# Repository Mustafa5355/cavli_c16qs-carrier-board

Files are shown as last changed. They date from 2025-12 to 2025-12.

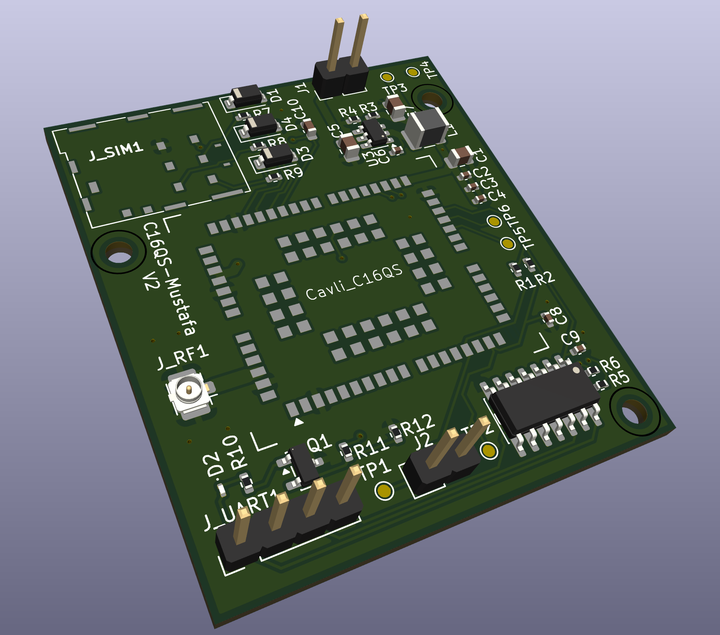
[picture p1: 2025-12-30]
PCB/c16qs-carrier-board.png

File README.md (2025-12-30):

# cavli_c16qs-carrier-board

This repository contains the complete hardware design for a 2-layer carrier board for the Cavli C16QS LTE Cat-1 bis module. The board provides regulated power, SIM card interface, RF antenna connection via u.FL, level-shifted UART communication to a 3.3 V host, and control/status signals.

The design is implemented in KiCad and follows Cavli's hardware guidelines for power integrity, RF layout, and SIM protection. It is intended as a reference carrier for evaluation, prototyping, and integration of the C16QS module into embedded systems.

Features:
- 5 V input with synchronous buck regulation to module VBAT
- Nano-SIM socket with ESD protection and signal conditioning
- u.FL connector for external LTE antenna
- Bidirectional UART level shifting between 1.8 V and 3.3 V domains
- Hardware power key, reset, and network status indication
- 2-layer, low-cost PCB optimized for EMI and signal integrity

The repository includes schematic, PCB layout, fabrication outputs, BOM, and design documentation.

## Footprint Note

The C16QS footprint included in this repository was created manually by the author using the published mechanical drawings and pin mapping of the C16QS module. It is designed to be reusable across projects and is suitable for prototyping and evaluation.

This footprint is not an official manufacturer CAD file. Users should verify alignment and pin mapping against the latest Cavli documentation before fabrication.

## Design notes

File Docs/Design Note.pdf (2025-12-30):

## Design Note — C16QS Carrier Board (v1)

### 1. Functional Overview

This board is a minimal-component carrier for the Cavli C16QS LTE Cat-1 bis module. It provides regulated power, level-shifted UART, SIM card interface, RF antenna connection, hardware control signals, and basic debug access.

The design follows Cavli’s reference hardware requirements for power, RF routing, SIM connectivity, and control interfaces.

### 2. Power Architecture

The board is powered from a 5 V external supply connected at J1. A synchronous buck regulator (AP62250WU) generates the module supply voltage VBAT.

The regulator output is set using the resistor divider R3 and R4 to approximately 3.8 V, which lies safely within the C16QS operating range.

The inductor L1 and capacitors C6 and C7 form the switching and output filter network recommended in the regulator datasheet. Additional local decoupling capacitors (C1–C4) are placed directly at the module’s VBAT pins to handle high-frequency current transients during LTE transmission.

The regulator is sized to handle the module’s peak current during transmit bursts, providing sufficient margin above the expected maximum load.

### 3. UART Level Shifting

The C16QS uses 1.8 V logic levels, while the external host operates at 3.3 V. A TXS0104ED bidirectional level translator is used to safely interface between these voltage domains.

VCCA is connected to the module’s 1.8 V domain and VCCB is connected to the 3.3 V host supply. Series resistors on the UART lines reduce ringing and EMI. The UART interface is brought out to J_UART1 for external connection and debugging.

### 4. USIM Interface

The SIM interface connects the C16QS to a nano-SIM socket. The clock, reset, and data lines include small series resistors for signal integrity. TVS diodes protect the SIM lines from ESD events caused by user insertion or removal.

Local decoupling is placed close to the SIM socket to stabilize the SIM supply and suppress noise.

### 5. RF and Antenna Layout

The RF output from the module is routed directly to a u.FL connector for an external LTE antenna.

The RF trace is kept short, straight, and free of stubs or vias. It is routed on the top layer over a continuous ground plane to maintain controlled impedance. Ground stitching vias surround the RF area and the connector shield pads to provide a low-inductance return path and reduce radiation.

Copper keep-out is enforced around the RF trace to prevent coupling from digital or switching signals.

### 6. Control, Reset, and Status

The power-key and reset signals are accessible through a header to allow external control and debugging.

A NET_STATUS output drives a transistor that switches a visible LED. This allows network status indication without loading or stressing the module’s GPIO.

### 7. Mechanical and Manufacturing

The PCB uses a simple two-layer construction to reduce cost and complexity. All components are surface-mount and compatible with standard automated assembly.

Mounting holes provide mechanical support. Silkscreen includes board identification and reference markings.

### 8. Compliance Summary

The design meets the C16QS hardware requirements for supply voltage range, peak current capability, SIM interface protection, RF impedance control, logic-level compatibility, and required control signals.

### 9. Conclusion

This carrier board provides a stable, electrically compliant, and manufacturable platform for integrating the C16QS LTE module into host systems. The design emphasizes power integrity, RF signal quality, and interface protection while keeping the BOM and layout simple.

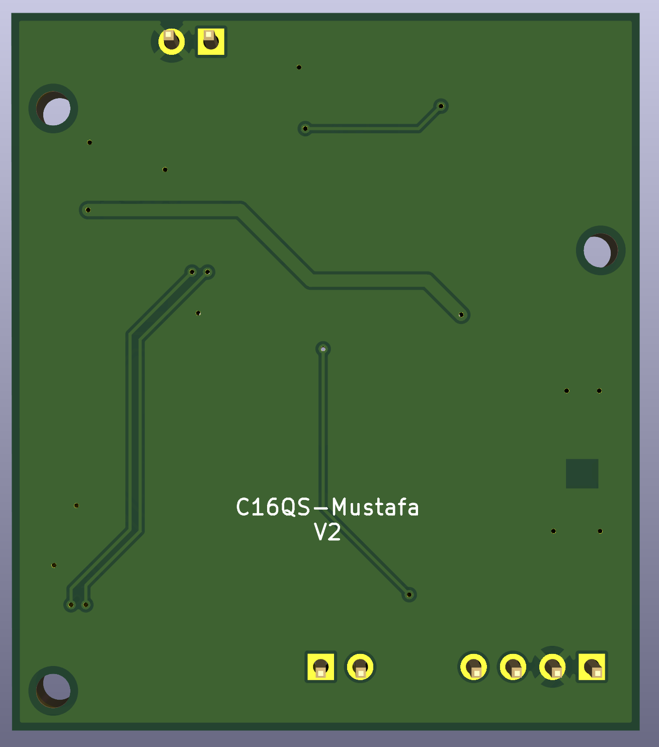
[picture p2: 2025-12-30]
PCB/c16qs-carrier-board (3).png

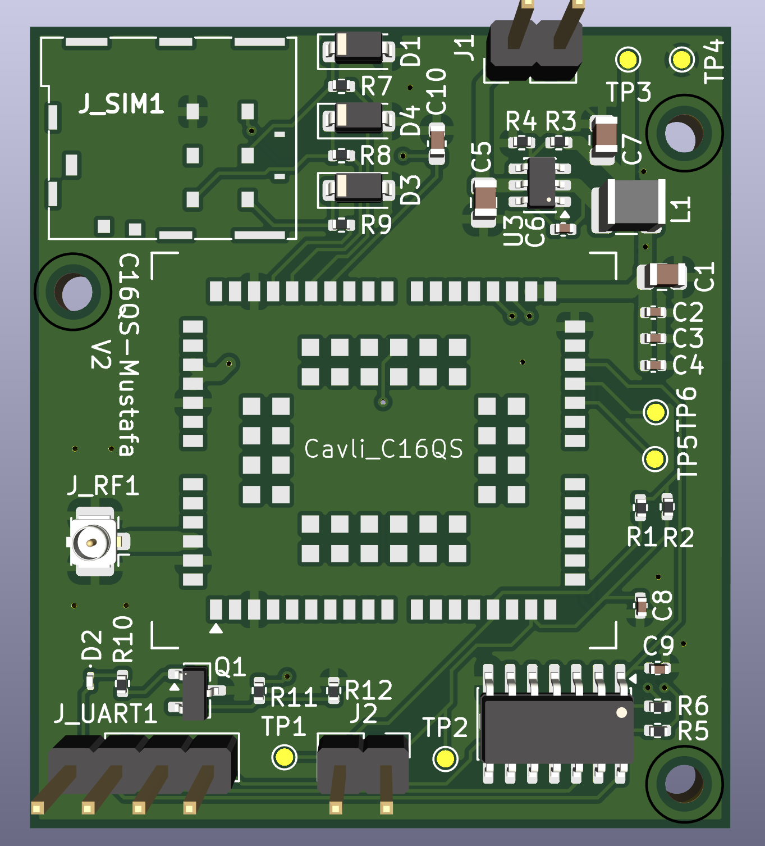
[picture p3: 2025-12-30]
PCB/c16qs-carrier-board (2).png

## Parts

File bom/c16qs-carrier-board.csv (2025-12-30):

Id | Designator | Footprint | Quantity | Designation | Supplier and ref
1 | R11,R1 | R_0402_1005Metric | 2 | 4.7k
2 | C10 | C_0603_1608Metric | 1 | 1uF
3 | R10 | R_0402_1005Metric | 1 | 2.2k
4 | C6,C9,C2,C8 | C_0402_1005Metric | 4 | 0.1uF
5 | R2 | R_0402_1005Metric | 1 | 10k
6 | J1,J2 | PinHeader_1x02_P2.54mm_Vertical | 2 | Conn_01x02
7 | C7,C5,C1 | C_0805_2012Metric | 3 | 22uF
8 | R4 | R_0402_1005Metric | 1 | 100k
9 | C4 | C_0402_1005Metric | 1 | 33pF
10 | U3 | TSOT-23-6 | 1 | AP62250WU
11 | R5,R9,R7,R6,R8 | R_0402_1005Metric | 5 | 22
12 | L1 | L_1210_3225Metric | 1 | 2.2uH
13 | Q1 | SOT-23 | 1 | NPN
14 | J_RF1 | U.FL_Hirose_U.FL-R-SMT-1_Vertical | 1 | Conn_Coaxial_Small
15 | D3,D1,D4 | D_SOD-123 | 3 | SMF15A
16 | TP2,TP4,TP6,TP5,TP3,TP1 | TestPoint_Pad_D1.0mm | 6 | TestPoint
17 | U_UART_LS1 | SOIC-14_3.9x8.7mm_P1.27mm | 1 | TXS0104ED
18 | R3 | R_0402_1005Metric | 1 | 374k
19 | C3 | C_0402_1005Metric | 1 | 10pF
20 | D2 | LED_0201_0603Metric | 1 | LED
21 | J_SIM1 | JAE_SIM_Card_SF72S006 | 1 | JAE_SIM_Card_SF72S006
22 | R12 | R_0402_1005Metric | 1 | 47k
23 | U1 | C16QS | 1 | ~
24 | J_UART1 | PinHeader_1x04_P2.54mm_Vertical | 1 | Conn_01x04

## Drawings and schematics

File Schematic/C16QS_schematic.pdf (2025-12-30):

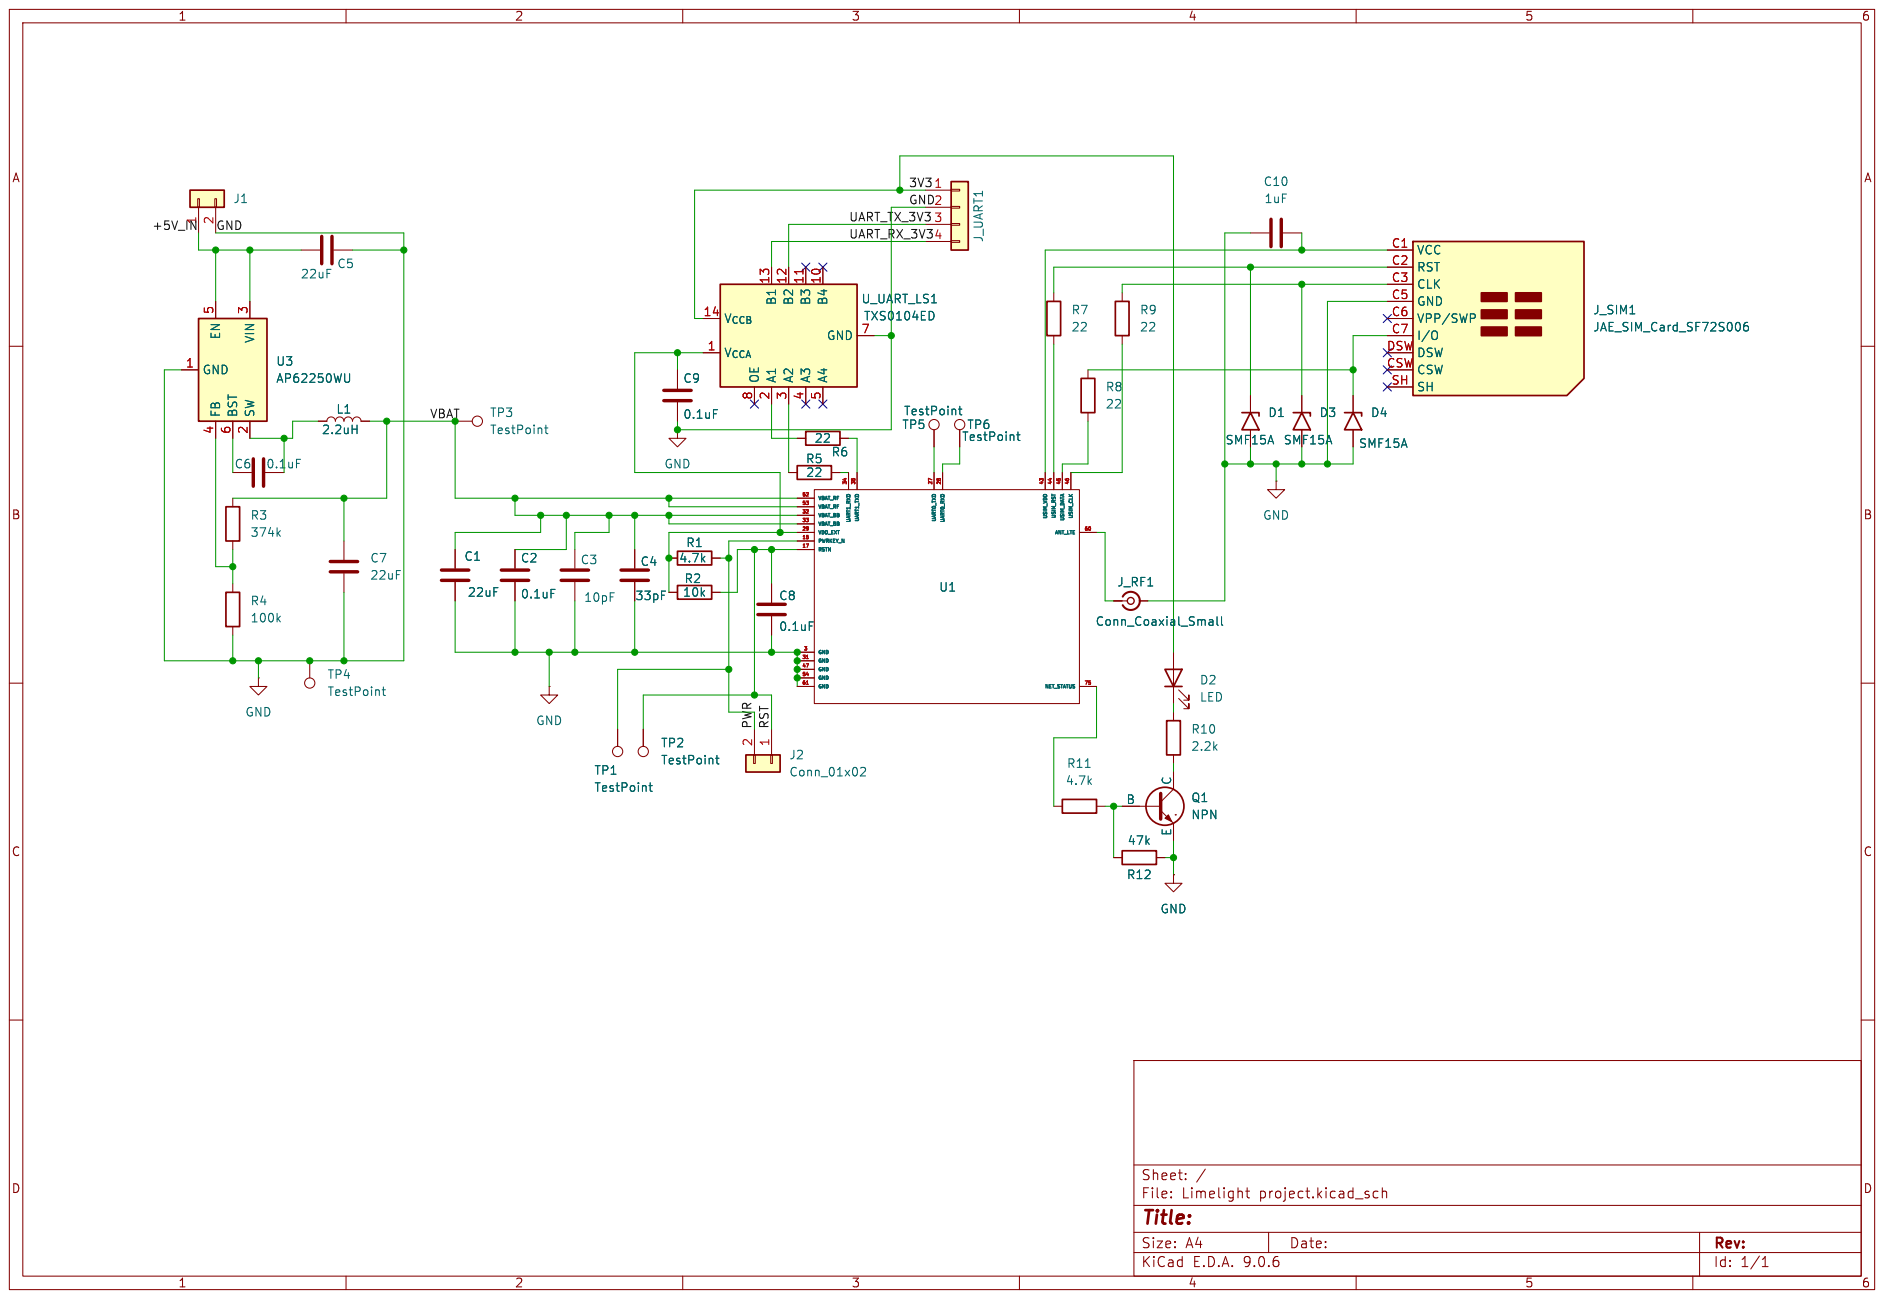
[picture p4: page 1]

JAE_SIM_Card_SF72S006 VCC C1 RST C2 CLK C3 GND C5 VPP/SWP C6

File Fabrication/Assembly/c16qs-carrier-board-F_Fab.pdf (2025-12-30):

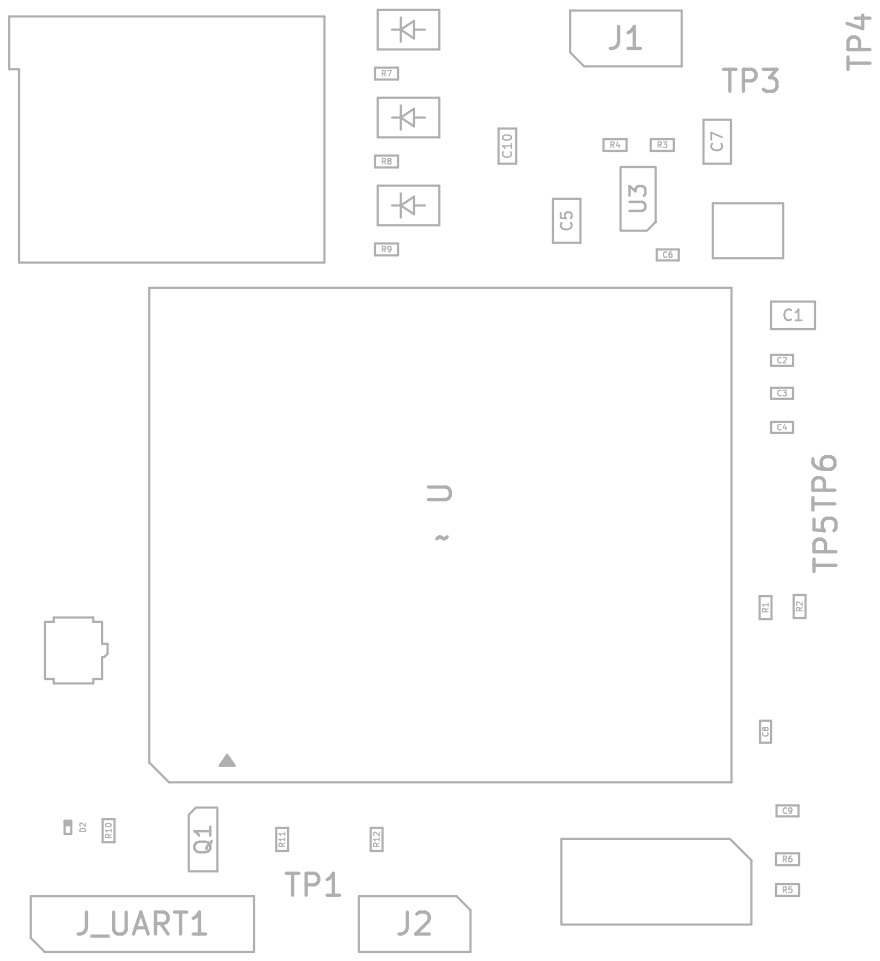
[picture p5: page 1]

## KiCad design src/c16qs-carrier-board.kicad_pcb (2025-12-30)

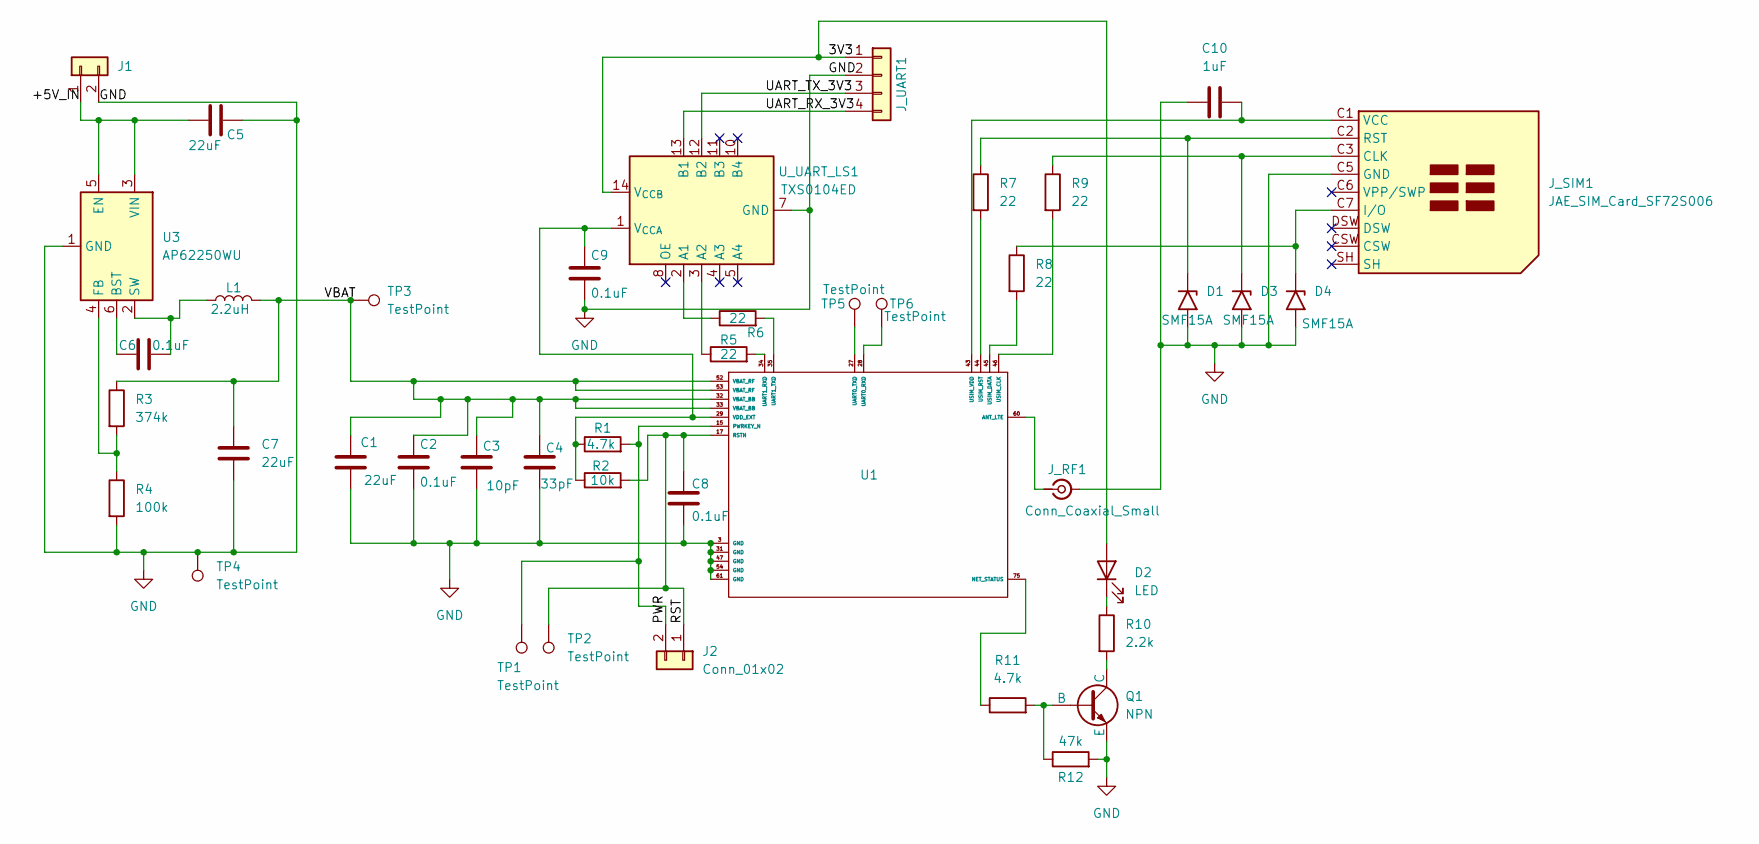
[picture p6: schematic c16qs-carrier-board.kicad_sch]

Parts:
C1, C5, C7: 22uF; C_0805_2012Metric
C2, C6, C8, C9: 0.1uF; C_0402_1005Metric
C3: 10pF; C_0402_1005Metric
C4: 33pF; C_0402_1005Metric
C10: 1uF; C_0603_1608Metric
D1, D3, D4: SMF15A; D_SOD-123
D2: LED; LED_0201_0603Metric
J1, J2: Conn_01x02; PinHeader_1x02_P2.54mm_Vertical
J_RF1: Conn_Coaxial_Small; U.FL_Hirose_U.FL-R-SMT-1_Vertical
J_SIM1: JAE_SIM_Card_SF72S006
J_UART1: Conn_01x04; PinHeader_1x04_P2.54mm_Vertical
L1: 2.2uH; L_1210_3225Metric
Q1: NPN; SOT-23
R1, R11: 4.7k; R_0402_1005Metric
R2: 10k; R_0402_1005Metric
R3: 374k; R_0402_1005Metric
R4: 100k; R_0402_1005Metric
R5, R6, R7, R8, R9: 22; R_0402_1005Metric
R10: 2.2k; R_0402_1005Metric
R12: 47k; R_0402_1005Metric
TP1, TP2, TP3, TP4, TP5, TP6: TestPoint; TestPoint_Pad_D1.0mm
U1: C16QS
U3: AP62250WU; TSOT-23-6
U_UART_LS1: TXS0104ED; SOIC-14_3.9x8.7mm_P1.27mm

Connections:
/3V3: D2.2 (A), J_UART1.1, U_UART_LS1.14 (V_{CCB})
/+5V_IN: C5.2, J1.1, U3.3 (VIN), U3.5 (EN)
/PWR: J2.2, R1.2, TP1.1, U1.15 (PWRKEY_N)
/RST: C8.1, J2.1, R2.2, TP2.1, U1.17 (RSTN)
/UART_RX_3V3: J_UART1.4, U_UART_LS1.13 (B1)
/UART_TX_3V3: J_UART1.3, U_UART_LS1.12 (B2)
/VBAT: C1.1, C2.1, C3.1, C4.1, C7.1, L1.2, R3.1, TP3.1, U1.32 (VBAT_BB), U1.33 (VBAT_BB), U1.52 (VBAT_RF), U1.53 (VBAT_RF)
GND: C1.2, C2.2, C3.2, C4.2, C5.1, C7.2, C8.2, C9.2, C10.1, D1.2 (A2), D3.2 (A2), D4.2 (A2), J1.2, J_RF1.2 (Ext), J_SIM1.C5 (GND), J_UART1.2, Q1.3 (E), R4.2, R12.2, TP4.1, U1.3 (GND), U1.31 (GND), U1.47 (GND), U1.54 (GND), U1.61 (GND), U3.1 (GND), U_UART_LS1.7 (GND)
unnamed: D1.1 (A1), J_SIM1.C2 (RST), R7.1
unnamed: D2.1 (K), R10.1
unnamed: D3.1 (A1), J_SIM1.C3 (CLK), R9.1
unnamed: D4.1 (A1), J_SIM1.C7 (I/O), R8.1
unnamed: J_RF1.1 (In), U1.60 (ANT_LTE)
unnamed: C10.2, J_SIM1.C1 (VCC), U1.43 (USIM_VDD)
unnamed: Q1.2 (B), R11.2, R12.1
unnamed: Q1.1 (C), R10.2
unnamed: R11.1, U1.75 (NET_STATUS)
unnamed: TP6.1, U1.28 (UART0_RXD)
unnamed: TP5.1, U1.27 (UART0_TXD)
unnamed: R5.2, U1.34 (UART1_RXD)
unnamed: R6.2, U1.35 (UART1_TXD)
unnamed: R9.2, U1.46 (USIM_CLK)
unnamed: R8.2, U1.45 (USIM_DATA)
unnamed: R7.2, U1.44 (USIM_RST)
unnamed: C9.1, R1.1, R2.1, U1.29 (VDD_EXT), U_UART_LS1.1 (V_{CCA})
unnamed: C6.1, U3.6 (BST)
unnamed: R3.2, R4.1, U3.4 (FB)
unnamed: C6.2, L1.1, U3.2 (SW)
unnamed: R6.1, U_UART_LS1.2 (A1)
unnamed: R5.1, U_UART_LS1.3 (A2)

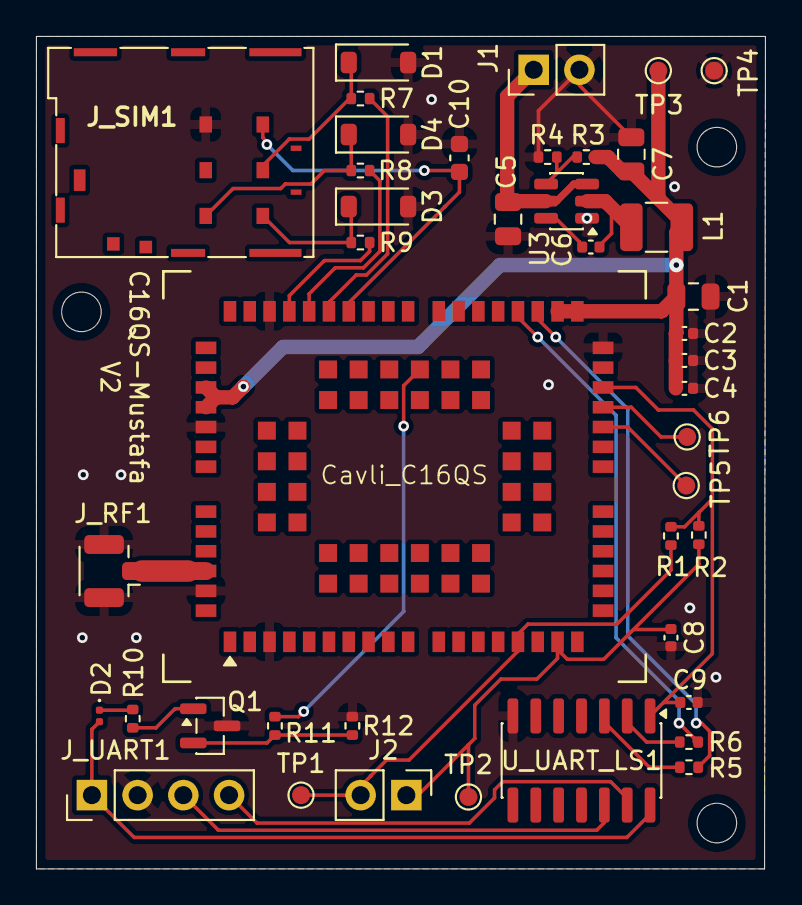
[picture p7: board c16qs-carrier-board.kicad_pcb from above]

Board: 2 copper layers, 40.5 x 46.2 mm, 42 parts (0 on the bottom side), 30 nets.
